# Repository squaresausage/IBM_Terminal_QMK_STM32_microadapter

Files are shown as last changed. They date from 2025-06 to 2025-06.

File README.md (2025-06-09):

# IBM_Terminal_QMK_STM32_microadapter

My attempt to design a very small and very cheap USB converter for IBM Model M terminal keyboards.

Intended to fit in between the pins of a 5 pin DIN 270° female connector, with a PCB edge USB A connector.

V0.2 now should actually match the pins of a DIN connector. Make sure to use the updated version of the keyboard config with the latest pinout for the F042.

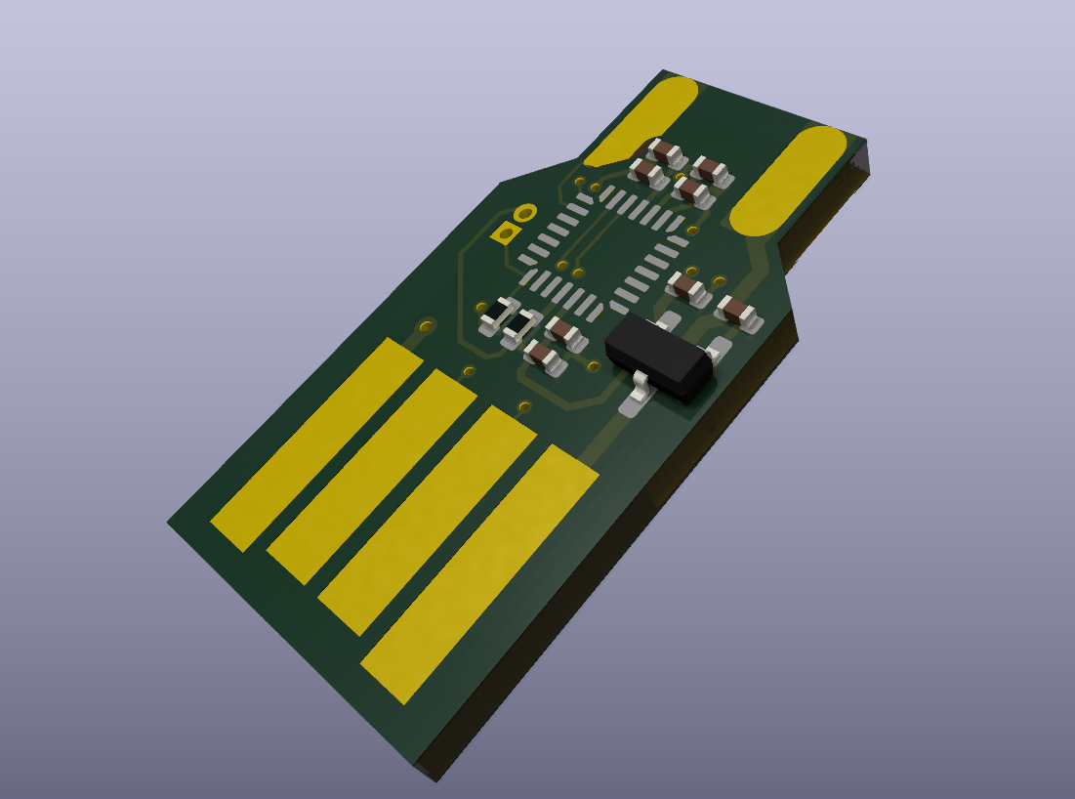
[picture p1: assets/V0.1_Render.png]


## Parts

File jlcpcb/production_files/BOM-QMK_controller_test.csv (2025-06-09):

Comment | Designator | Footprint | LCSC
10n | C4,C8 | C_0402_1005Metric | C15195
100n | C5 | C_0402_1005Metric | C1525
10K | R1,R2 | R_0402_1005Metric | C25744
1u | C1,C2,C3,C6,C7 | C_0402_1005Metric | C52923
XC6206PxxxMR | U2 | SOT-23-3 | C5446
STM32F042G6Ux | U1 | QFN-28_4x4mm_P0.5mm | C961597

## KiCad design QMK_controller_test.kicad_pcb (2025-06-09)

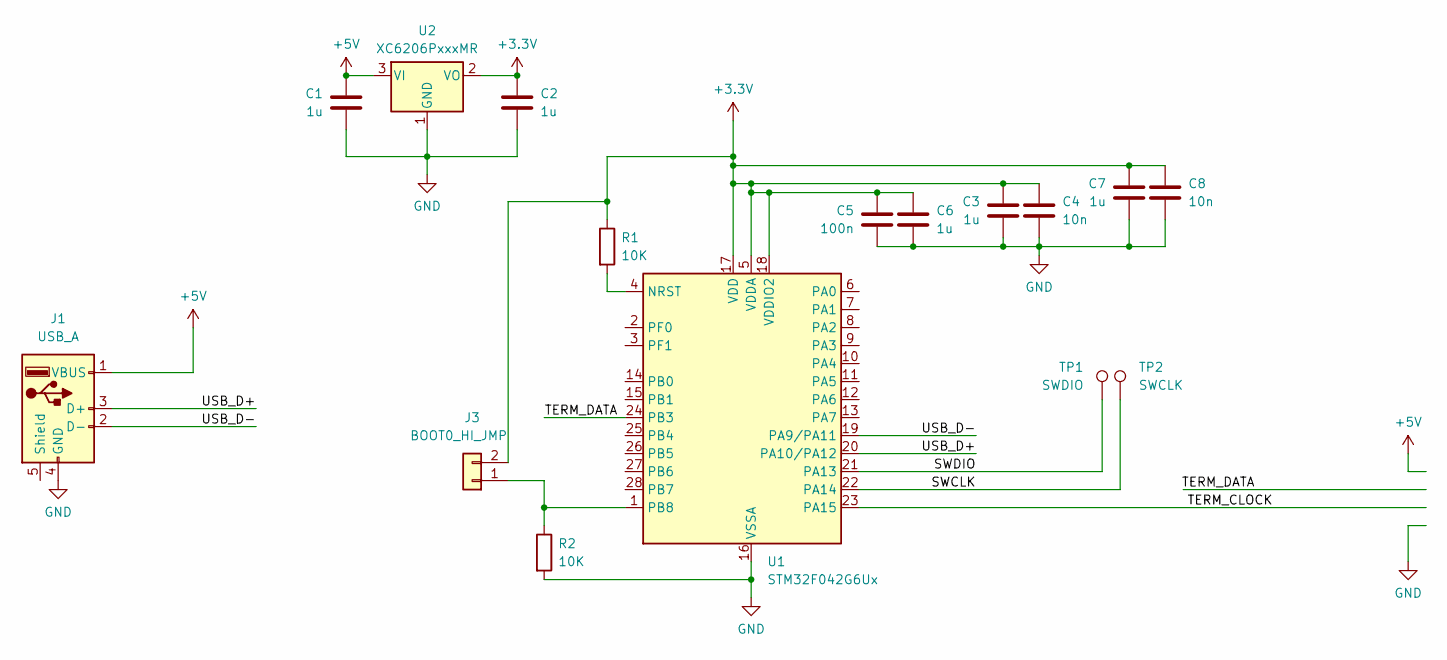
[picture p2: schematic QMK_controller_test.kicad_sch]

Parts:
C1, C2, C3, C6, C7: 1u; C_0402_1005Metric; LCSC C52923
C4, C8: 10n; C_0402_1005Metric; LCSC C15195
C5: 100n; C_0402_1005Metric; LCSC C1525
J1: USB_A; usb-PCB
J3: BOOT0_HI_JMP; PinHeader_1x02_P1.00mm_Vertical
R1, R2: 10K; R_0402_1005Metric; LCSC C25744
TP1: SWDIO; TestPoint_Pad_D1.0mm
TP2: SWCLK; TestPoint_Pad_D1.0mm
U1: STM32F042G6Ux; QFN-28_4x4mm_P0.5mm; LCSC C961597
U2: XC6206PxxxMR; SOT-23-3; LCSC C5446

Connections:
+3.3V: C2.1, C3.1, C4.1, C5.1, C6.1, C7.1, C8.1, J3.2, R1.1, U1.5 (VDDA), U1.17 (VDD), U1.18 (VDDIO2), U2.2 (VO)
+5V: C1.1, J1.1 (VBUS), U2.3 (VI)
/SWCLK: TP2.1, U1.22 (PA14)
/SWDIO: TP1.1, U1.21 (PA13)
/TERM_CLOCK: U1.23 (PA15)
/TERM_DATA: U1.24 (PB3)
/USB_D+: J1.3 (D+), U1.20 (PA10/PA12)
/USB_D-: J1.2 (D-), U1.19 (PA9/PA11)
GND: C1.2, C2.2, C3.2, C4.2, C5.2, C6.2, C7.2, C8.2, J1.4 (GND), R2.2, U1.16 (VSSA), U2.1 (GND)
unnamed: J3.1, R2.1, U1.1 (PB8)
unnamed: R1.2, U1.4 (NRST)

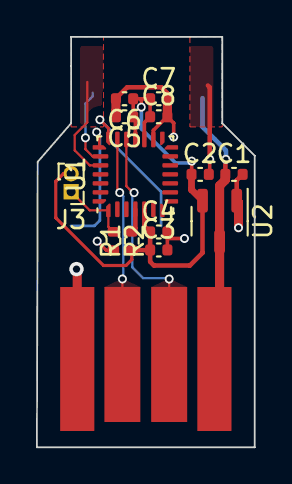
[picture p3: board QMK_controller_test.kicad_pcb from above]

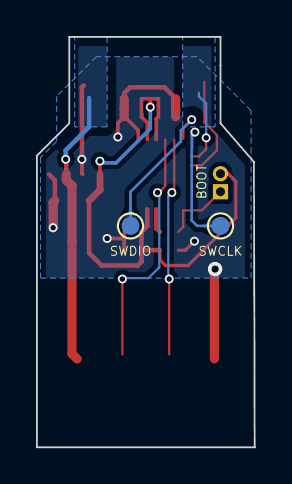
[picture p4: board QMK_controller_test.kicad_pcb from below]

Board: 2 copper layers, 12.1 x 22.8 mm, 16 parts (2 on the bottom side), 9 nets.

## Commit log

2025-06-09 Init Commit
    [BOM-QMK_controller_test.csv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]
2025-06-09 V0.2 - Fixed broken DIN 5 pinout. Fixed SWD conflict pinout (PB3 - DATA, PA15 - CLOCK). Also added SWD testpoints.
    [QMK_controller_test.kicad_pcb, QMK_controller_test.kicad_sch]
